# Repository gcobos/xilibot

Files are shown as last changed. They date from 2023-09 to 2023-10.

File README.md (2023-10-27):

# XiliBot

A self-balancing robot with a LCD screen to show faces, and a color sensor at its bottom.

In the hardware side, this repository contains the FreeCAD model, STL pieces to print, and PCB circuit desing in KiCAD.

In the software area, it includes the robot source code, which is a modified version of the [B-Robot EVO2](https://github.com/jjrobots/B-ROBOT_EVO2),
a remote controller made in Unity3D that uses [UnityOSC](https://thomasfredericks.github.io/UnityOSC) library to send commands to the robot,
and a [Web controller](web/index.html) that uses [Blockly](https://developers.google.com/blockly/) to control the robot using visual programming.
Blockly requires to start [python/webserver.py](python/server/webserver.py) to be able to send UDP packages to the robot.

This robot uses a Wemos D1 mini as the "brains", and it is configured to create its own access point, so that the controller connects to the robot's wifi.

## Xilibot standing



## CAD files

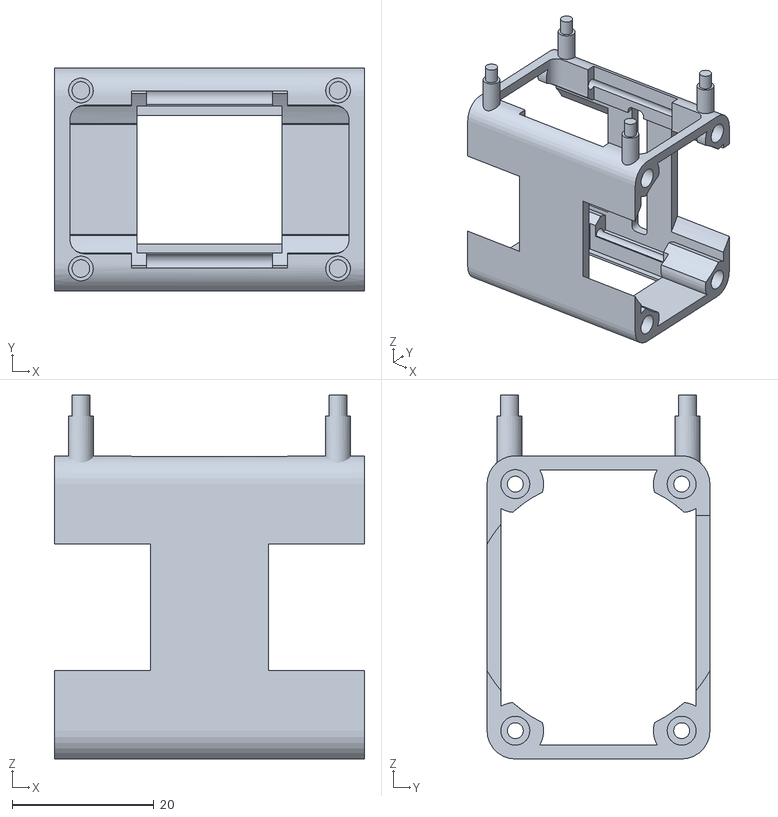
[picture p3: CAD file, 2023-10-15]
cad/xilibot-base.stl
43.8 x 31.5 x 51.4

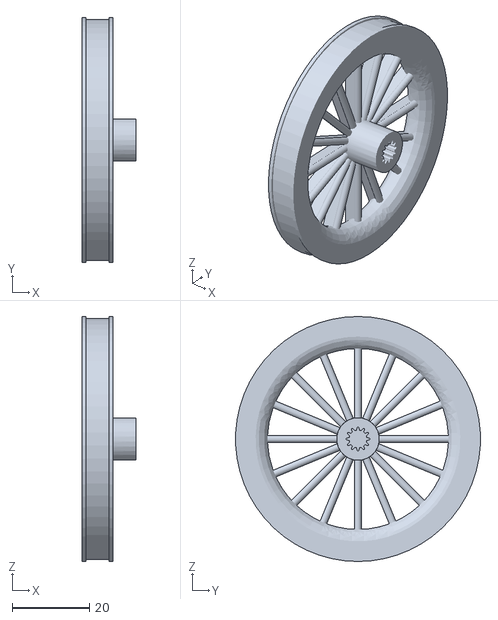
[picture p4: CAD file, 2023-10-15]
cad/Wheel.stl
14.0 x 63.4 x 63.5

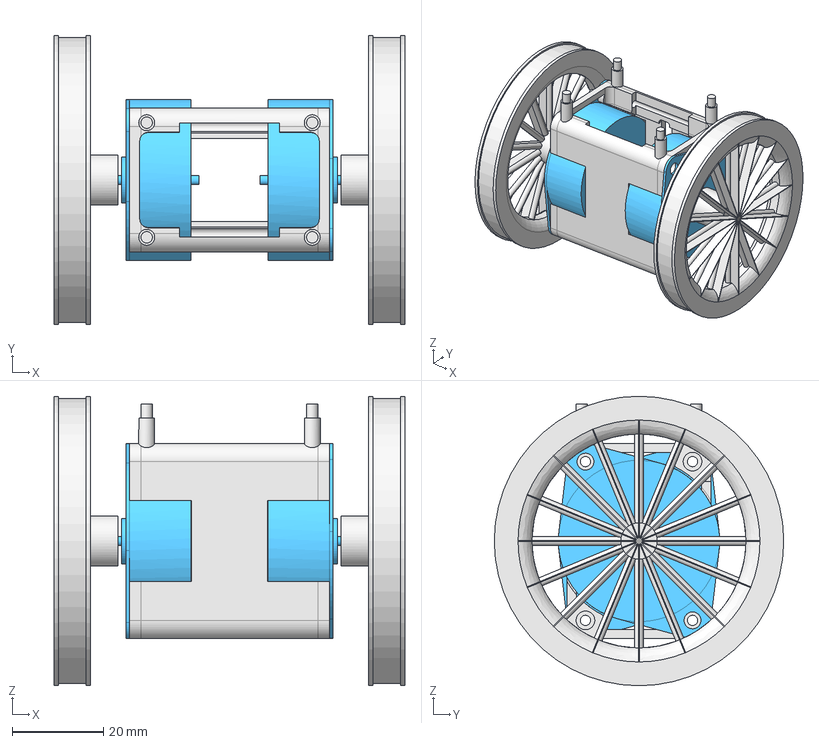
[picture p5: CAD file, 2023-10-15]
cad/xilitol-robot.FCStd
77.0 x 63.5 x 63.5 mm
Motor02
Wheel02

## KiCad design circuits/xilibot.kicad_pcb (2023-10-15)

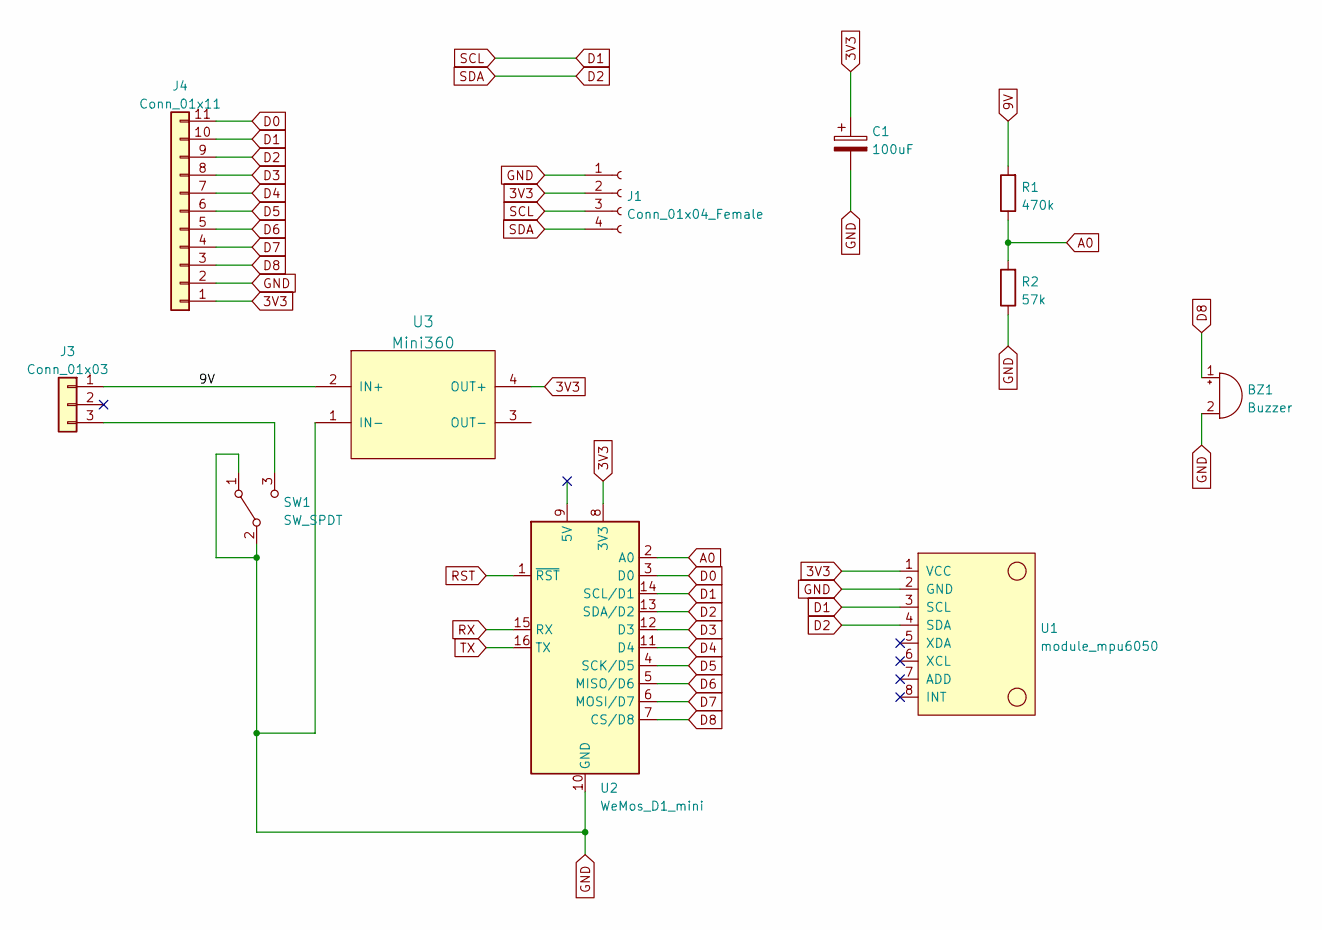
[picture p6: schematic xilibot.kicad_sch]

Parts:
BZ1: Buzzer; Buzzer_12x9.5RM7.6
C1: 100uF; C_Radial_D6.3mm_H5.0mm_P2.50mm
J1: Conn_01x04_Female; PinHeader_1x04_P2.54mm_Horizontal
J3: Conn_01x03; PinSocket_1x03_P2.54mm_Vertical
J4: Conn_01x11; PinSocket_1x11_P2.54mm_Vertical
R1: 470k; R_Axial_DIN0204_L3.6mm_D1.6mm_P2.54mm_Vertical
R2: 57k; R_Axial_DIN0204_L3.6mm_D1.6mm_P2.54mm_Vertical
SW1: SW_SPDT; SW_CuK_JS202011CQN_DPDT_Straight
U1: module_mpu6050
U2: WeMos_D1_mini; WEMOS_D1_mini_light
U3: Mini360; Mini360_step-down

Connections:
3V3: C1.1, J1.2, J4.1, U1.1 (VCC), U2.8 (3V3), U3.4 (OUT+)
9V: J3.1, R1.2, U3.2 (IN+)
A0: R1.1, R2.2, U2.2 (A0)
D0: J4.11, U2.3 (D0)
D1: J1.3, J4.10, U1.3 (SCL), U2.14 (SCL/D1)
D2: J1.4, J4.9, U1.4 (SDA), U2.13 (SDA/D2)
D3: J4.8, U2.12 (D3)
D4: J4.7, U2.11 (D4)
D5: J4.6, U2.4 (SCK/D5)
D6: J4.5, U2.5 (MISO/D6)
D7: J4.4, U2.6 (MOSI/D7)
D8: BZ1.1 (-), J4.3, U2.7 (CS/D8)
GND: BZ1.2 (+), C1.2, J1.1, J4.2, R2.1, SW1.1 (A), SW1.2 (B), U1.2 (GND), U2.10 (GND), U3.1 (IN-)
unnamed: J3.3, SW1.3 (C)
RST: U2.1 (~RST)
RX: U2.15 (RX)
TX: U2.16 (TX)

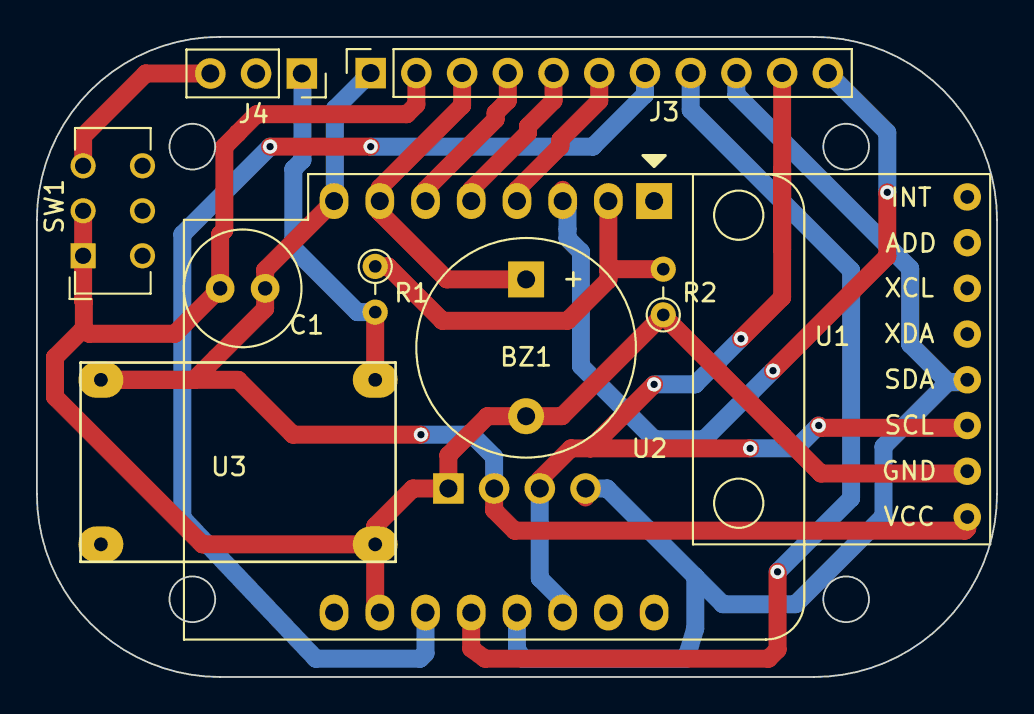
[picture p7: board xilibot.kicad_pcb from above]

Board: 2 copper layers, 53.3 x 35.6 mm, 11 parts (1 on the bottom side), 14 nets.

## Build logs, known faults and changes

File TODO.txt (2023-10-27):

x Organizar el código para que vuelva a compilar en platformio
x Hacer una cara más decente
x Soldar el LED al pin del INT
x Cambiar el robot al nuevo soporte impreso
x Usar el TCS34725_async y reconocer los colores
x Arreglar el control via WEB para el robot
x Depurar el controlador (demasiado giro (quiere decir que hay que reducir el número de pulsos))
x Ajustar el equilibro del robot (estabilidad)
x Hacer el controlador desde Unity o kivy
x La dirección de los giros está bien, pero adelante y atrás están invertidos
x Animación de las caras
x Hacer que el robot genere su propio AP con ip/password fijos
- Hacer interfaz para leer el voltaje de la batería
- Hacer interfaz para leer el color
- Programar la traducción de los colores en acciones
- Ajustar los valores del robot para que se levante más fácilmente cuando se caiga
x Mejorar la estabilidad dinámica (cuando es empujado, o cuando se balancea, etc)
- Diseñar la carcasa en 3D
- OTA uploads!!
x Añadir modelos 3D + circuitos + App control remoto + screenshots

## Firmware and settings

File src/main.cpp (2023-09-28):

// This one takes lots of code from:
// BROBOT EVO 2 by JJROBOTS
// SELF BALANCE ARDUINO ROBOT WITH STEPPER MOTORS
// License: GPL v2

#include <Arduino.h>
#include <Wire.h>
//#include <SPI.h>
#include <defines.hpp>
// OLED display
#ifdef ENABLE_DISPLAY
#include <U8g2lib.h>
#endif
// Color sensor
#ifdef ENABLE_COLOR_SENSOR
#include <Adafruit_TCS34725.h>
#include <color_detection.hpp>
#endif
// Wifi connection
#include <ESP8266WiFi.h>
#include <credentials.hpp>
#include "../gfx/despierto1.xbm"
#include "../gfx/dormido1.xbm"

extern volatile int32_t steps1;
extern volatile int32_t steps2;
extern int32_t target_steps1;
extern int32_t target_steps2;
extern float PID_errorSum;

extern float Kp_thr;
extern float Ki_thr;
extern float Kp_position;
extern float Kd_position;
extern float Kp;
extern float Kd;

extern int16_t OSCmove_speed;
extern int16_t OSCmove_steps1;
extern int16_t OSCmove_steps2;

extern uint8_t OSCnewMessage;
extern uint8_t OSCpage;
extern uint8_t OSCmove_mode;

extern bool modifing_control_parameters;

// Actual speed of motors
extern int16_t speed_M1, speed_M2;

extern int8_t dir_M1, dir_M2;

extern float angle_offset;
extern float angle_adjusted_filtered;
bool fallen = true;

extern long timer_old;
extern long timer_prev;
extern long timer_value;

// Angle of the robot (used for stability control)
float angle_adjusted;
float angle_adjusted_Old;

float dt;

float estimated_speed_filtered; // Estimated robot speed
int16_t actual_robot_speed; // overall robot speed (measured from steppers speed)

int16_t motor1;
int16_t motor2;

int16_t motor1_control;
int16_t motor2_control;

uint8_t mode = 0; // mode = 0 Normal mode, mode = 1 Pro mode (More aggressive)

boolean positionControlMode = false;

float control_output;
float max_target_angle = MAX_TARGET_ANGLE;

int16_t throttle;
float steering;
float max_throttle = MAX_THROTTLE;
float max_steering = MAX_STEERING;

float target_angle;

uint8_t cascade_control_loop_counter = 0;
uint8_t loop_counter;		 // To generate a medium loop 40Hz
uint8_t slow_loop_counter;	 // slow loop 2Hz
uint8_t sendBattery_counter; // To send battery status
int16_t BatteryValue;

#ifdef ENABLE_DISPLAY
U8G2_SH1106_128X64_NONAME_F_HW_I2C display(U8G2_R0, /* reset=*/ U8X8_PIN_NONE);
#endif

#ifdef ENABLE_COLOR_SENSOR

Adafruit_TCS34725 tcs = Adafruit_TCS34725(TCS34725_INTEGRATIONTIME_614MS, TCS34725_GAIN_1X);

uint8_t     sensorColor;
uint16_t    red, green, blue, clear;
volatile bool sensorReady = false;

// Reads
void getRGB_noDelay(uint16_t *r, uint16_t *g, uint16_t *b, uint16_t *c)
{
	uint16_t tmp_r, tmp_g, tmp_b, tmp_c;

	GPOS = (1 << TCS_LED_PIN);
	tmp_c = tcs.read16(TCS34725_CDATAL);
	tmp_r = tcs.read16(TCS34725_RDATAL);
	tmp_g = tcs.read16(TCS34725_GDATAL);
	tmp_b = tcs.read16(TCS34725_BDATAL);

	// Avoid divide by zero errors ... if clear = 0 return black
	if (tmp_c == 0) {
		*r = *g = *b = *c = 0;
		return;
	}
	uint16_t sum = tmp_c;

	*r = (float)tmp_r / sum * 255.0;
	*g = (float)tmp_g / sum * 255.0;
	*b = (float)tmp_b / sum * 255.0;
	GPOC = (1 << TCS_LED_PIN);
}

#endif

void setup()
{
	// Turn off the very bright blue led
	GPOS = (1 << LED_BUILTIN);

	Serial.begin(115200);
	Serial.print("Initiating...");

	// Configure pins
	pinMode(DIR_M1_PIN, OUTPUT);			// DIR MOTOR 1
	pinMode(STEP_M1_PIN, OUTPUT);			// STEP MOTOR 1
	pinMode(DIR_M2_PIN, OUTPUT);			// DIR MOTOR 2
	pinMode(STEP_M2_PIN, OUTPUT);			// STEP MOTOR 2
	pinMode(MOTOR_ENABLE_PIN, OUTPUT);		// ENABLE MOTORS PIN AS OUTPUT
	pinMode(TCS_LED_PIN, OUTPUT);			// TCS LED
	pinMode(BUZZER_PIN, OUTPUT);			// BUZZER
	digitalWrite(MOTOR_ENABLE_PIN, HIGH);   // Motors disabled
	digitalWrite(TCS_LED_PIN, LOW);         // TCS LED off

	// Make the buzzer sound
	// do not use tone() because it causes conflicts with timer1 used for the steppers!
	digitalWrite(BUZZER_PIN, HIGH); delay(10); digitalWrite(BUZZER_PIN, LOW);
	delay(10); 
	digitalWrite(BUZZER_PIN, HIGH); delay(10); digitalWrite(BUZZER_PIN, LOW);
#ifdef CREATE_WIFI_AP
	WiFi.softAPConfig({192,168,4,1}, {192,168,4,1}, {255,255,255,0}); // local IP, gateway, subnet
	if (WiFi.softAP(WIFI_SSID, WIFI_PASS, 1, 0, 1)) {
		Serial.print("Access Point is created with SSID: ");
		Serial.println(WIFI_SSID);
		Serial.print("Access Point IP: ");
		Serial.println(WiFi.softAPIP());
	} else {
		Serial.println("Unable to Create Access Point");
	}
	Serial.printf("Now listening at IP %s, UDP port %d\n", WiFi.softAPIP().toString().c_str(), UDP_RECV_PORT);
#else
	WiFi.begin(WIFI_SSID, WIFI_PASS);
	while (WiFi.status() != WL_CONNECTED)
	{
		delay(500);
		Serial.print(":");
	}
	Serial.println("connected to AP");
	Serial.printf("Now listening at IP %s, UDP port %d\n", WiFi.localIP().toString().c_str(), UDP_RECV_PORT);
#endif
	UDP.begin(UDP_RECV_PORT);

	OSC_init();

	// Initialize I2C bus (MPU6050 is connected via I2C)
	// join I2C bus (I2Cdev library doesn't do this automatically)
	Wire.begin();
	Wire.setClock(500000); // 500kHz I2C clock. Comment this line if having compilation difficulties

	Serial.println("XILIBOT");
	delay(200);
	
	Serial.println(F("Initializing I2C devices..."));
#ifdef ENABLE_DISPLAY
	if (!display.begin()) {
		Serial.println(F("SH1106 allocation failed"));
	}
	display.firstPage();
	display.setFont(u8g2_font_6x12_mr);
	// Export as XBM and use this header: const unsigned char face1_bits[] U8X8_PROGMEM = {
	//display.drawXBM(0, 0, 128, 64, face_sad_bits);
	display.drawXBM(0, 0, 128, 64, dormido1_bits);
	//display.updateDisplay();
	//display.sendBuffer();
	display.nextPage();
#endif
	Serial.println("Don't move!");
	delay(500);
	MPU6050_setup();  // setup MPU6050 IMU
	delay(500);

  	// Calibrate MPU gyros
  	MPU6050_calibrate();

	digitalWrite(BUZZER_PIN, HIGH); delay(300); digitalWrite(BUZZER_PIN, LOW); 

#ifdef ENABLE_COLOR_SENSOR
	sensorColor = COLOR_NONE;
	while (!tcs.begin()) {
		Serial.println(F("TCS34725 NOT found"));
    	delay(1000);
	}
	Serial.println(F("Found color sensor"));
#endif

	// STEPPER MOTORS INITIALIZATION
	Serial.println("Steppers init");
	// Enable stepper drivers and TIMER interrupts

	initStepperMotors();

	setMotorSpeedM1(0);               // Motor1 stopped
	dir_M1 = 0;

	setMotorSpeedM2(0);               // Motor2 stopped
	dir_M2 = 0;

	digitalWrite(MOTOR_ENABLE_PIN, LOW);   // Enable motors

  	Serial.println("Start...");
  	timer_old = micros();
	timer_prev = timer_old;
}

void loop()
{
	OSC_MsgRead();  // Read UDP OSC messages
	delay(0);
	if (OSCnewMessage)
	{
		OSCnewMessage = 0;
		if (OSCpage == 1)   // Get commands from user (PAGE1 are user commands: throttle, steering...)
		{
			if (modifing_control_parameters)  // We came from the settings screen
			{
				OSCfader[0] = 0.5; // default neutral values
				OSCfader[1] = 0.5;
				OSCtoggle[0] = 0;  // Normal mode
				mode = 0;
				modifing_control_parameters = false;
			}

			if (OSCmove_mode)
			{
#ifdef DEBUG
				Serial.print("MOVE ");
				Serial.print(OSCmove_speed);
				Serial.print(" ");
				Serial.print(OSCmove_steps1);
				Serial.print(",");
				Serial.println(OSCmove_steps2);
#endif				
				positionControlMode = true;
				OSCmove_mode = false;
				// Flip the sign here because front and back are inverted
				target_steps1 = steps1 - OSCmove_steps1;
				target_steps2 = steps2 - OSCmove_steps2;
			}
			else
			{
#ifdef DEBUG
				Serial.println("THROTTLE");
#endif
				positionControlMode = false;
				throttle = (OSCfader[0] - 0.5) * -max_throttle;
				// We add some exponential on steering to smooth the center band
				steering = OSCfader[1] - 0.5;
				if (steering > 0)
				steering = (steering * steering + 0.5 * steering) * max_steering;
				else
				steering = (-steering * steering + 0.5 * steering) * max_steering;
#ifdef DEBUG
				Serial.print(throttle);
				Serial.print(" ");
				Serial.println(steering);
#endif
			}

			if ((mode == 0) && (OSCtoggle[0]))
			{
#ifdef DEBUG
				Serial.println("MODE 0");
#endif
				// Change to PRO mode
				max_throttle = MAX_THROTTLE_PRO;
				max_steering = MAX_STEERING_PRO;
				max_target_angle = MAX_TARGET_ANGLE_PRO;
				mode = 1;
			}
			if ((mode == 1) && (OSCtoggle[0] == 0))
			{
#ifdef DEBUG
				Serial.println("MODE 1");
#endif
				// Change to NORMAL mode
				max_throttle = MAX_THROTTLE;
				max_steering = MAX_STEERING;
				max_target_angle = MAX_TARGET_ANGLE;
				mode = 0;
			}
		}
		else if (OSCpage == 2) { // OSC page 2
#ifdef DEBUG
				Serial.println("READ PARAMS");
#endif
			// Check for new user control parameters
			readControlParameters();
		}

	} // End new OSC message

	timer_value = micros();

	// New IMU data?
	if (MPU6050_newData())
	{
		MPU6050_read_3axis();
		loop_counter++;
		slow_loop_counter++;
		dt = (timer_value - timer_old) * 0.000001; // dt in seconds
		timer_old = timer_value;

		angle_adjusted_Old = angle_adjusted;
		// Get new orientation angle from IMU (MPU6050)
		float MPU_sensor_angle = MPU6050_getAngle(dt);
		angle_adjusted = MPU_sensor_angle + angle_offset;
		if ((MPU_sensor_angle>-15) && (MPU_sensor_angle<15)) {
			angle_adjusted_filtered = angle_adjusted_filtered*0.99 + MPU_sensor_angle*0.01;
		}
/*	
	#ifdef DEBUG
		Serial.print(dt);
		Serial.print(" ");
		Serial.print(angle_offset);
		Serial.print(" ");
		Serial.print(angle_adjusted);
		Serial.print(",");
		Serial.println(angle_adjusted_filtered);
	#endif

	#ifdef DEBUG
		Serial.printf("Steps1: %d, steps2: %d\n", steps1, steps2);
		//Serial.printf("OSC move_steps1: %d, OSC move_steps2: %d\n", OSCmove_steps1, OSCmove_steps2);
		//Serial.printf("OSC move_steps1: %d, OSC move_steps2: %d\n", OSCmove_steps1, OSCmove_steps2);
	#endif
*/
		// We calculate the estimated robot speed:
		// Estimated_Speed = angular_velocity_of_stepper_motors(combined) - angular_velocity_of_robot(angle measured by IMU)
		actual_robot_speed = (speed_M1 + speed_M2) / 2; // Positive: forward  

		int16_t angular_velocity = (angle_adjusted - angle_adjusted_Old) * 25.0; // 25 is an empirical extracted factor to adjust for real units
		int16_t estimated_speed = -actual_robot_speed + angular_velocity;
		estimated_speed_filtered = estimated_speed_filtered * 0.9 + (float)estimated_speed * 0.1; // low pass filter on estimated speed
/*
	#ifdef DEBUG
		Serial.print(angle_adjusted);
		Serial.print(" ");
		Serial.println(estimated_speed_filtered);
	#endif
*/
		if (positionControlMode)
		{
			// POSITION CONTROL. INPUT: Target steps for each motor. Output: motors speed
			motor1_control = positionPDControl(steps1, target_steps1, Kp_position, Kd_position, speed_M1);
			motor2_control = positionPDControl(steps2, target_steps2, Kp_position, Kd_position, speed_M2);

			// Convert from motor position control to throttle / steering commands
			throttle = (motor1_control + motor2_control) / 2;
			throttle = constrain(throttle, -190, 190);
			steering = motor2_control - motor1_control;
			steering = constrain(steering, -50, 50);
		}

		// ROBOT SPEED CONTROL: This is a PI controller.
		//    input:user throttle(robot speed), variable: estimated robot speed, output: target robot angle to get the desired speed
		target_angle = speedPIControl(dt, estimated_speed_filtered, throttle, Kp_thr, Ki_thr);
		target_angle = constrain(target_angle, -max_target_angle, max_target_angle); // limited output

	#if DEBUG==3
		Serial.print(angle_adjusted);
		Serial.print(" ");
		Serial.print(estimated_speed_filtered);
		Serial.print(" ");
		Serial.println(target_angle);
	#endif

		// Stability control (100Hz loop): This is a PD controller.
		//    input: robot target angle(from SPEED CONTROL), variable: robot angle, output: Motor speed
		//    We integrate the output (sum), so the output is really the motor acceleration, not motor speed.
		control_output += stabilityPDControl(dt, angle_adjusted, target_angle, Kp, Kd);
		control_output = constrain(control_output, -MAX_CONTROL_OUTPUT, MAX_CONTROL_OUTPUT); // Limit max output from control

		// The steering part from the user is injected directly to the output
		motor1 = control_output + steering;
		motor2 = control_output - steering;

		// Limit max speed (control output)
		motor1 = constrain(motor1, -MAX_CONTROL_OUTPUT, MAX_CONTROL_OUTPUT);
		motor2 = constrain(motor2, -MAX_CONTROL_OUTPUT, MAX_CONTROL_OUTPUT);

		int angle_ready;
		if (OSCpush[0])     // If we press the SERVO button we start to move
			angle_ready = 82;
		else
			angle_ready = 74;  // Default angle
		if ((angle_adjusted < angle_ready) && (angle_adjusted > -angle_ready)) // Is robot ready (upright?)
		{
			// NORMAL MODE
#ifdef ENABLE_DISPLAY
			if (fallen) {
				display.drawXBM(0, 0, 128, 64, despierto1_bits);
				display.nextPage();
				fallen = false;
			}
#endif
			GPOC = (1 << MOTOR_ENABLE_PIN);  // Motors enable
			// NOW we send the commands to the motors
			// NOTE: Change here forward-to-backward and left-to-right movement
			setMotorSpeedM1(motor1);
			setMotorSpeedM2(motor2);
		} else  {  // Robot not ready (flat), angle > angle_ready => ROBOT OFF	
#ifdef ENABLE_DISPLAY
			if (!fallen) {
				display.drawXBM(0, 0, 128, 64, dormido1_bits);
				display.nextPage();
				fallen = true;
			}
#endif
			GPOS = (1 << MOTOR_ENABLE_PIN);  // Disable motors
			setMotorSpeedM1(0);
			setMotorSpeedM2(0);
			PID_errorSum = 0;  // Reset PID I term
			Kp = KP_RAISEUP;   // CONTROL GAINS FOR RAISE UP
			Kd = KD_RAISEUP;
			Kp_thr = KP_THROTTLE_RAISEUP;
			Ki_thr = KI_THROTTLE_RAISEUP;
			// RESET steps
			steps1 = 0;
			steps2 = 0;
			target_steps1 = 0;
			target_steps2 = 0;
			positionControlMode = false;
			OSCmove_mode = false;
			throttle = 0;
			steering = 0;
		}
		
		// Normal condition?
		if ((angle_adjusted < 56) && (angle_adjusted > -56))
		{
			setDefaultControlGains();
		}
		else    // We are in the raise up procedure => we use special control parameters
		{
			setRaiseUpControlGains();
		}

	}    // End of new IMU 

	// Medium loop 7.5Hz
	if (loop_counter >= 15)
	{
		loop_counter = 0;

	} // End of medium loop
	else if (slow_loop_counter >= 100) // 1Hz
	{
		slow_loop_counter = 0;

#ifdef DEBUG
		Serial.printf("Target steps? %d, %d, Current steps: %d, %d\n", target_steps1, target_steps2, steps1, steps2);
#endif

#ifdef ENABLE_COLOR_SENSOR
		// Read only when speed < 1, and turn the led on before reading
		if (estimated_speed_filtered < 0.5 && fabs(angle_adjusted) < 20) {
			if (sensorReady) {
				sensorColor = detectColor(red, green, blue);
			} else {
				getRGB_noDelay(&red, &green, &blue, &clear);
			}
			sensorReady = !sensorReady;
		}
#endif
		//Serial.printf("\nTime:\n%d\n", timer_value - timer_prev);
		timer_prev = timer_value;
		//Serial.printf("\nSpeed: %f, Angle: %f\n", estimated_speed_filtered, angle_adjusted);
#ifdef ENABLE_DISPLAY
		//uint16_t max_color = max(max(r, g), b);
		//r = map(r, 0, max_color, 0, 255);
		//g = map(g, 0, max_color, 0, 255);
		//b = map(b, 0, max_color, 0, 255);
		/*display.print("R:");
		display.println(r, DEC);
		display.print("G:");
		display.println(g, DEC);
		display.print("B:");
		display.println(b, DEC);
		//display.println(ColorNameString(r, g, b));
		//display.printf("\nTime:\n%d\n", timer_value - timer_prev);
		display.printf("Temp: %d\n", colorTemp);
		*/
		//display.printf("%d", target_steps1);
		//display.nextPage();
#ifdef ENABLE_COLOR_SENSOR
		const char *colorNames[] = {
			"BLACK",
			"PINK",
			"PURPLE",
			"BLUE",
			"LIGHTBLUE",
			"CYAN",
			"GREEN",
			"YELLOW",
			"ORANGE",
			"RED",
			"WHITE",
		};
		/*
		if (sensorColor < 0 || sensorColor > 10) {
			Serial.println("NO COLOR");
			//display.drawStr(0, 10, "NO COLOR");
			//GPOC = (1 << BUZZER_PIN);
		} else {
			if (sensorColor == COLOR_BLUE || sensorColor == COLOR_LIGHTBLUE) {
				//GPOS = (1 << BUZZER_PIN);
				Serial.println(colorNames[sensorColor]);
			}
			sensorColor = COLOR_NONE;
			//display.drawStr(0, 20, colorNames[sensorColor]);
		}
		*/
		//display.updateDisplay();
		
		//display.printf("Lux: %d\n", lux);
		//Serial.printf("R: %d, G: %d, B: %d\n", red, green, blue);
#endif
		//display.printf("Angle: %f\n", angle_adjusted);
		//display.printf("M1: %d\n", motor1);
		//display.printf("M2: %d\n", motor2);
		//display.printf("Speed: %d\n", actual_robot_speed);
		//display.display();
		//Serial.printf("M1: %d\n", motor1);
		//Serial.printf("M2: %d\n", motor2);
		//Serial.println(ColorNameString(r, g, b));
		//display.updateDisplay();
#endif

	}  // End of slow loop
}

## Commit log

2023-09-15 Color detection working, but interrupts make noise on the MPU
    [main.cpp]
2023-09-20 Fixes direction of throttle and target steps
    [main.cpp]
2023-10-15 Add CAD and circuits
    [Wheel.stl, xilibot-base.stl, xilibot.kicad_pcb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]
